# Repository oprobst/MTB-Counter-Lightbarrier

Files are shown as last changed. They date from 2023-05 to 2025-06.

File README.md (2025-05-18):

# Lichtschranke mit Unterbrechungszähler

Diese Implementierung wurde mit dem Hintergrund erstellt, auf einem Mountain-Bike Trail die Anzahl der Durchfahrten zu messen. Mit kleineren Anpassungen, kann diese Schaltung aber auch für alles Mögliche verwendet werden.

* Ziel ist es, die Unterbrechungen der Lichtschranke zu zählen. Dies wird über den gesamten Lebenszyklus, wie auch auf täglicher Basis gezählt.
* Weitere Anforderung ist ein möglichst geringer Stromverbrauch, um einen Einsatz mit Batterie im Feld zu vereinfachen.

# Bedienungsanleitung

An der rechten oberen Seite der Verteilerdose ist ein Magnetkontakt angebracht. Dieser kann genutzt werden, um das Display zu aktivieren. Sobald ein Magnet an das Gehäuse gehalten wird, aktiviert sich das Display für 5 Minuten. Im Normalbetrieb ist das Display aus, um Strom zu sparen und um zu verhindern, dass Fuchs und Hase daran herum spielen. Ein weiterer Vorteil des Magneten liegt darin, dass eine fehleranfällige Gehäusedurchführung für einen Taster eingespart werden kann.

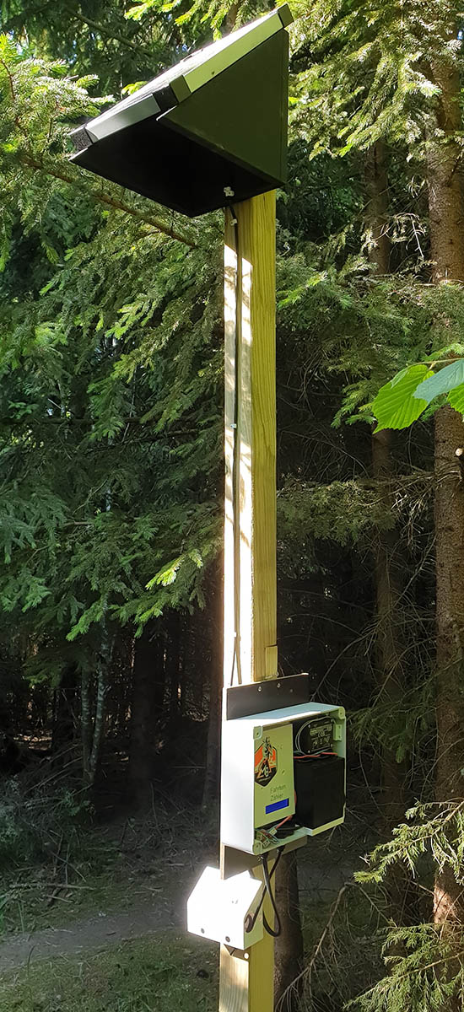
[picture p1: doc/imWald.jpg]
Installation des Zählers im Wald


## Display
Auf dem Display sind mehrere Zahlen abgebildet. Links oben ist die Gesamtzahl der aufgezeichneten Unterbrechungen. Diese Zahl wird mit jeder Durchfahrt um einen Zähler erhöht.

In der unteren Zeile sind die vergangenen Tage dokumentiert. Es wird immer dann eine neue Zählung begonnen, wenn der Helligkeitssensor einen Sonnenaufgang registriert oder wenn das System neu gestartet (oder resettet) wird.
Dabei steht jede Zahl für einen Tag. In dem unten abgebildeten Beispiel sind am heutigen Tag 15 Fahrten, gestern 0 und vorgestern 1 Unterbrechung gemessen worden. Der Speicher lässt nur 253 Zählungen zu, finden mehr Durchfahrten an einem Tag statt, so zeigt das Display 'MAX' an. Dies beeinflusst allerdings nicht die Zählung der gesamten Durchgänge oben links.

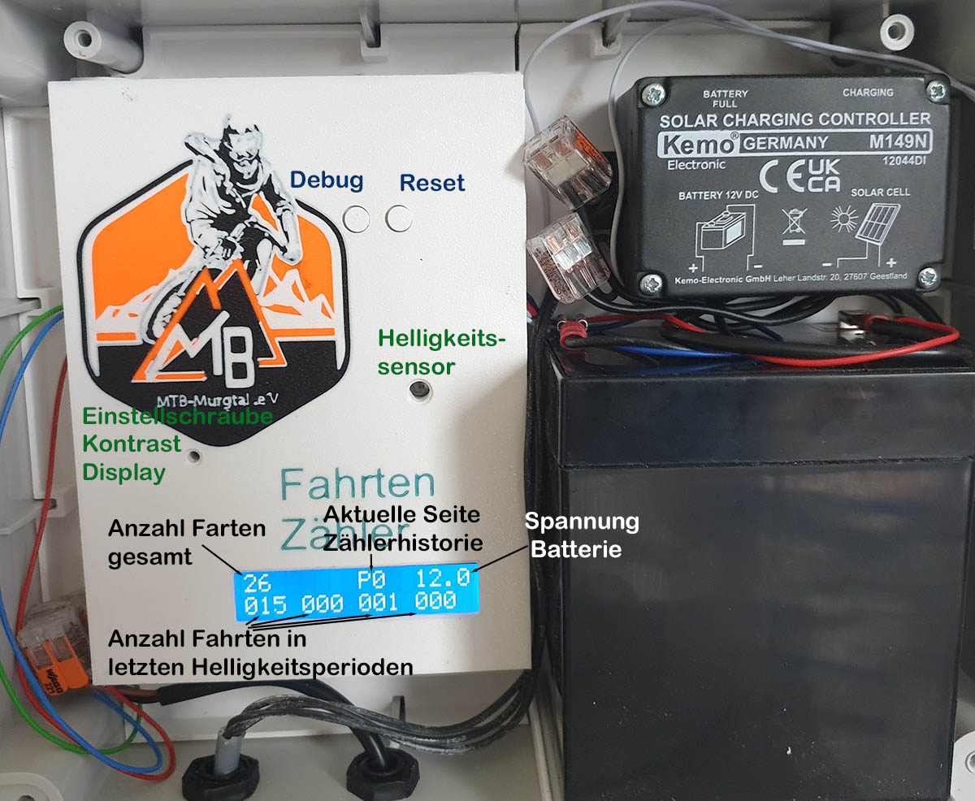
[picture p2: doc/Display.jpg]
Komponenten des Zählers


Um mehr als die letzten 4 Tage anzuzeigen, schaltet der Zähler mehrere Seiten durch. Dabei wird jede Seite wird für 5 Sekunden angezeigt. Im Beispiel befindet sich der Zähler noch auf Seite 0, visualisiert durch die Angabe 'P0'. Folglich wird in der Zeile unten auf erster Stelle der aktuelle Tag und im Weiteren die vergangenen drei Tage dargestellt.
Würde hier z.B. 'P3' stehen, so rechne man einfach die (Page)3 * 4(Tage) um auf den Tag des ersten Wertes in der Vergangenheit zu kommen. In diesem Fall würde man also die Durchfahrten von vor 12, vor 13, vor 14 und vor 15 Tagen angezeigt bekommen.

Letztlich steht ganz rechts oben eine Zahl mit einer Nachkommastelle. Hierbei handelt es sich um die aktuelle Batteriespannung. Sie muss im Regelfall zwischen 9V und 14V liegen. Liegt sie darunter, lädt die Solarzelle die Batterie nicht mehr. Liegt sie darüber, ist irgendetwas magisches passiert.

Der Kontrast des Displays lässt sich mit einer Stellschraube auf halber Höhe des Zählers einstellen.

## Zähler zurück setzen

Es ist möglich den Zähler auf 0 zurück zu setzen. Dafür muss der linke ('Debug') Knopf gedrückt und gehalten werden. Dann der rechte ('Reset' Knopf) kurz gedrückt werden, während der Debug Knopf für weitere 10 Sekunden gehalten werden muss. Das Display zählt einen Countdown herunter und meldet dann 'Speicher gelöscht'.

# Umsetzung

## Generelles Setup

Die Schaltung ist mit einer 10W Peak Solarzelle ausgestattet, die über einen Solarladeregler einen 5,4Ah Bleigelakku lädt. Diese versorgt die Schaltung über eine Sicherung (<=100mA ist ausreichend).
Aus der Versorgungsspannung wird die Lichtschranke direkt bedient und die Platine über einen 3,3V DC/DC Wandler betrieben.

Die reine Zählerschaltung (ohne den Batterie-Laderegler) benötigt - je nach Batteriespannung - etwa 4mA bei Tag und 0,7mA bei Nacht.

## Programmierung

Der Code ist nicht besonders schön und beruflich würde ich ihn dem Ersteller oder der Erstellerin um die Ohren hauen. Aber da ich das während eines Feierabend-Bierchens getippselt habe, setze ich mal andere Maßstäbe an.
Um die Programmierung einfach zu halten, werden die Arduino Libraries verwendet. Das ist nicht ganz durchgängig möglich, da die Pins für den Quarz als Input verwendet werden, was die Lib nicht vorsieht.

Wird die Lichtschranke unterbrochen, so findet für weitere 300ms keine weitere Messung mehr statt. Hierdurch wird verhindert, dass ein Arm und ein darauf folgender Oberkörper nicht als 2 Radfahrer erkannt werden.

Wird der Debug Knopf gedrückt und gehalten, so zeigt das Display den aktuell gemessenen Helligkeitswert (B:) an, sowie ein D für Day oder ein N für Night. Es folgt die Versorgungsspannungsmessung, sowie die Zählung des aktuellen Tages (C:) und die Dauer der letzten Unterbrechung (D:).

## Hardware
Als Microcontroller kommt der gute ATMega328P zum Einsatz. Um den Strombedarf gering zu halten, kommt der Zähler ohne externen Quarz und operiert auf lediglich 1 MHz per Fuses-Einstellung.
Dadurch liegt die maximale Auflösung bei 15ms. Grob über den Daumen gepeilt könnte es also sein, dass Radfahrer die mit mehr als 80 km/h auf dem Trail unterwegs sind nicht mehr erfasst werden.

Die aktuell erstellte Version wurde prototypisch auf einer Lochstreifenplatine erstellt. Spätere Versionen können bei erfolgreichem Dauertest auch auf professioneller gelayouteten Platinen umgesetzt werden.
Die momentane Implementierung speichert jeden Durchgang. Dadurch werden auch dann Zählungen gespeichert, wenn der Strom unerwartetet ausfällt. Nachteil ist die begrenzte Haltbarkeit des Speicherchips, der nur 100.000 Speichervorgänge garantiert.
Der Chip ist auf einen Sockel gesteckt und kann so einfach getauscht werden.

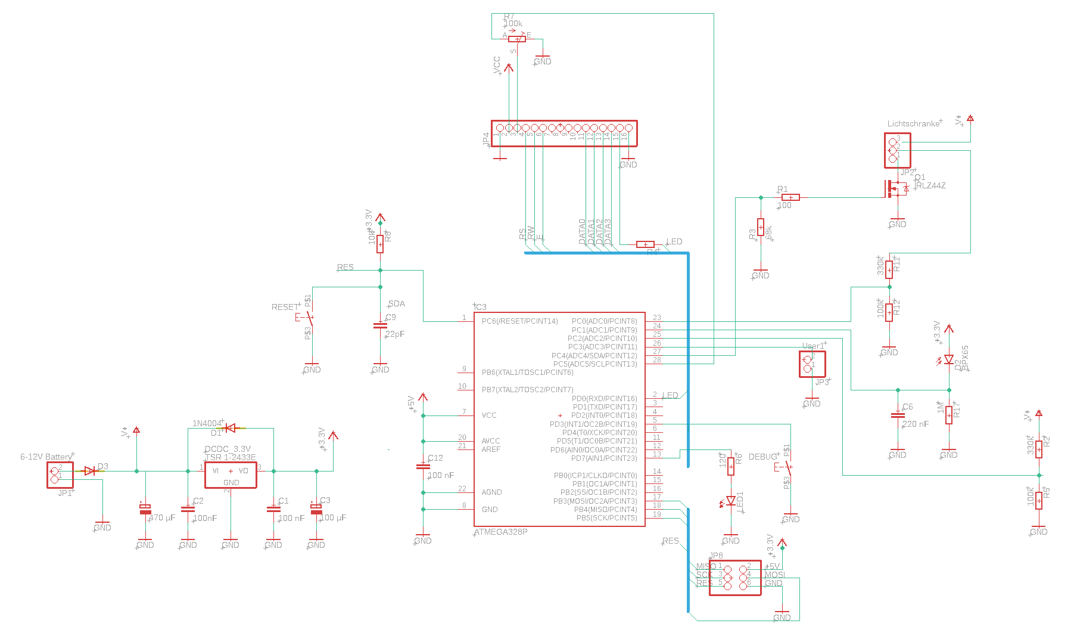
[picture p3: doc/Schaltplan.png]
Schaltplan


Generell sind die Widerstände eher großzügig zu Lasten den Genauigkeit dimensioniert mit dem Hintergedanken Strom zu sparen.

Die aktuelle Version arbeitet mit einem Hitatchi Display. Ich denke in den nächsten Versionen sollte ich dem Ganzen ein LCD Display spendieren, das ist irgendwie cooler und braucht auch nicht ganz so viele Datenleitungen. 

Als Phototransistor kommt der BP 103B-2 zum Einsatz. Für diesen Zweck nicht optimal, aber ich habe ihn mit einem sehr hohen Widerstand und einem Kondensator gebändigt. Dadurch ist die Messung sehr ungenau, aber um Hell und Dunkel zu unterscheiden reicht es.

Ein Verpolungsschutz wird durch eine Diode in Durchgangsrichtung realisiert. Auf die 0,7 Volt kommt es auch nicht mehr an. 

Zum Programmieren ist ein 6 poliger Standard Pinheader vorgesehen. Theoretisch muss man aufpassen, dass der Programmer mit 3,3V arbeitet, praktisch kann das Teil eine kurze Überspannung auf 5 V während des Programmierens ab.

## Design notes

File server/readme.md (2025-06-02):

🚴 Bike Counter API (Arduino Fahrrad-Zähler Schnittstelle)
Diese API dient als Schnittstelle für einen Arduino-basierten Fahrradzähler. Sie empfängt tägliche Zähldaten und einzelne Fahrten vom Arduino und speichert sie in einer MariaDB-Datenbank. Darüber hinaus bietet sie verschiedene Endpunkte zum Abrufen von Zähldaten, Tageszusammenfassungen und zum Export in CSV-Formaten.

🌟 Features
POST-Endpunkt: Empfängt tägliche Berichte (Gesamtzählung, Batteriestatus, Start-/Endzeiten und individuelle Fahrten-Zeitstempel) vom Arduino.
GET-Endpunkte:
Tägliche Zusammenfassungen der Fahrten.
Einzelne Fahrten für spezifische Tage (JSON).
CSV-Export von einzelnen Fahrten (/api/rides-csv) mit Zählernummer, Datum und Uhrzeit.
CSV-Export von täglichen Berichten (/api/report-csv) mit aggregierten Tagesdaten.
Abfrage des aktuellen Batteriestatus.
Abfrage des aktuellen Gesamtzählerstands.
API-Statusprüfung.
Authentifizierung: Basic Authentication für den POST-Endpunkt.
Datenbank: MariaDB (getestet mit MariaDB 10).
Technologie: PHP 8.3.
🛠️ Installation
Voraussetzungen
Webserver (z.B. Apache, Nginx) mit PHP 8.3 oder höher
MariaDB 10 oder höher Datenbankserver
Ein Datenbankbenutzer mit den notwendigen Berechtigungen (SELECT, INSERT, UPDATE, DELETE auf die bike_counter Datenbank)
1. Datenbank einrichten
Die benötigte Datenbank- und Tabellenstruktur ist in der Datei MariaDB-DDL.sql im Projektverzeichnis definiert. Führe dieses Skript auf deinem MariaDB-Server aus:

Bash

mysql -u your_db_user -p < MariaDB-DDL.sql
Oder führe den Inhalt manuell über ein Tool wie phpMyAdmin oder DBeaver aus.

SQL

-- Inhalt von MariaDB-DDL.sql
CREATE DATABASE IF NOT EXISTS `bike_counter` CHARACTER SET utf8mb4 COLLATE utf8mb4_unicode_ci;

USE `bike_counter`;

CREATE TABLE IF NOT EXISTS `daily_reports` (
    `id` INT AUTO_INCREMENT PRIMARY KEY,
    `transmission_date` DATETIME NOT NULL,
    `measurement_date` DATE NOT NULL UNIQUE,
    `start_time` TIME NOT NULL,
    `end_time` TIME NOT NULL,
    `daily_count` INT NOT NULL DEFAULT 0,
    `total_count_ever` INT NOT NULL DEFAULT 0,
    `battery_voltage` DECIMAL(4, 2) NOT NULL,
    `created_at` TIMESTAMP DEFAULT CURRENT_TIMESTAMP,
    `updated_at` TIMESTAMP DEFAULT CURRENT_TIMESTAMP ON UPDATE CURRENT_TIMESTAMP
) ENGINE=InnoDB DEFAULT CHARSET=utf8mb4 COLLATE=utf8mb4_unicode_ci;

CREATE TABLE IF NOT EXISTS `bike_rides` (
    `id` INT AUTO_INCREMENT PRIMARY KEY,
    `daily_report_id` INT NOT NULL,
    `measurement_date` DATE NOT NULL,
    `ride_time` TIME NOT NULL,
    `second_of_day` INT NOT NULL,
    `created_at` TIMESTAMP DEFAULT CURRENT_TIMESTAMP,
    CONSTRAINT `fk_daily_report`
        FOREIGN KEY (`daily_report_id`) REFERENCES `daily_reports`(`id`)
        ON DELETE CASCADE
) ENGINE=InnoDB DEFAULT CHARSET=utf8mb4 COLLATE=utf8mb4_unicode_ci;

-- Optional: Falls eine View daily_ride_summary existiert oder erstellt werden soll
-- CREATE VIEW daily_ride_summary AS ...;
2. API-Dateien hochladen
Lade die bike_counter.php-Datei (und alle anderen relevanten Dateien wie openapi.yaml, config-template.properties, MariaDB-DDL.sql in dein Webserver-Verzeichnis hoch (z.B. htdocs/mtb-club/). Die öffentliche URL sollte dann etwa https://www.your-domain.de/mtb-club/bike_counter.php/ sein.

3. Konfiguration (config.properties)
Das Projekt enthält die Datei config-template.properties. Um die API zu konfigurieren, führe folgende Schritte aus:

Benenne die Datei config-template.properties um in config.properties.
Fülle die umbenannte Datei mit deinen tatsächlichen Zugangsdaten und Einstellungen.
<!-- end list -->

Properties

# Inhalt von config-template.properties (Beispiel)
# Datenbank-Zugangsdaten
DB_HOST=localhost
DB_PORT=3306
DB_NAME=bike_counter
DB_USER=your_db_user
DB_PASSWORD=your_db_password
DB_CHARSET=utf8mb4

# API Basic Authentication
BASIC_AUTH_USER=your_api_username
BASIC_AUTH_PASSWORD=your_api_password

# API Pfad-Tiefe (Anzahl der Segmente vor /api/ im URL-Pfad, z.B. 2 für /mtb-club/bike_counter.php/api)
API_DEPTH=2 # Passe dies an deine Server-Umgebung an!

# Zeitzone für Zeitstempel (z.B. Europe/Berlin, America/New_York)
TIMEZONE=Europe/Berlin

# Minimale und maximale Batteriespannung für Validierung (optional)
MIN_BATTERY_VOLTAGE=10.0
MAX_BATTERY_VOLTAGE=15.0

# Debug-Modus (optional, 'true' oder 'false')
DEBUG_MODE=false

# API Version (optional)
API_VERSION=1.0
Wichtig: Die config.properties sollte niemals in einem öffentlichen Repository eingecheckt werden, da sie sensible Daten (Passwörter) enthält. Sie ist in der .gitignore-Datei dieses Projekts aufgeführt.

4. Datei-Encoding prüfen
Stelle sicher, dass die bike_counter.php-Datei selbst als UTF-8 ohne BOM gespeichert ist. Dies ist entscheidend für die korrekte Anzeige von Umlauten und Sonderzeichen in der API-Ausgabe und den CSV-Dateien.

🚀 Nutzung der API
Alle API-Endpunkte beginnen mit https://www.oliver-probst.de/mtb-club/bike_counter.php/api/.

POST-Endpunkte
POST /daily-report: Empfängt einen JSON-Payload mit täglichen Zähldaten und einzelnen Fahrten.
Authentifizierung: Basic Auth erforderlich.
Siehe OpenAPI Spezifikation für Details zum Request Body.
GET-Endpunkte
GET /daily-summary: Ruft tägliche Zusammenfassungen der Fahrten ab.
Query-Parameter: start_date=YYYY-MM-DD, end_date=YYYY-MM-DD
GET /rides: Ruft einzelne Fahrten für einen bestimmten Tag ab (JSON-Format).
Query-Parameter: date=YYYY-MM-DD
GET /rides-csv: Lädt eine CSV-Datei mit allen einzelnen Fahrten herunter (enthält Zählernummer pro Durchfahrt, Datum, Uhrzeit).
Query-Parameter: start_date=YYYY-MM-DD, end_date=YYYY-MM-DD
GET /report-csv: Lädt eine CSV-Datei mit den täglichen Berichten (Tageszusammenfassungen) herunter.
Query-Parameter: start_date=YYYY-MM-DD, end_date=YYYY-MM-DD
GET /battery-status: Ruft den letzten aufgezeichneten Batteriestatus ab.
GET /total-count: Ruft den letzten aufgezeichneten Gesamtzählerstand ab.
GET /status: Überprüft den API-Status und die Version.
📄 OpenAPI Spezifikation
Eine vollständige OpenAPI 3.0 Spezifikation der API befindet sich im Projektverzeichnis. Du kannst sie in Tools wie Swagger UI oder Postman importieren, um die API interaktiv zu erkunden und zu testen.

Link zur openapi.yaml

📝 Lizenz
Dieses Projekt ist unter der MIT-Lizenz lizenziert. Weitere Informationen findest du in der LICENSE-Datei. ---
Hinweis: Ersetze die Platzhalter wie https://www.your-domain.de/mtb-club/bike_counter.php/ und den Pfad zum Logo durch deine tatsächlichen Werte. Du solltest auch eine LICENSE-Datei hinzufügen, wenn du eine Lizenz angeben möchtest.

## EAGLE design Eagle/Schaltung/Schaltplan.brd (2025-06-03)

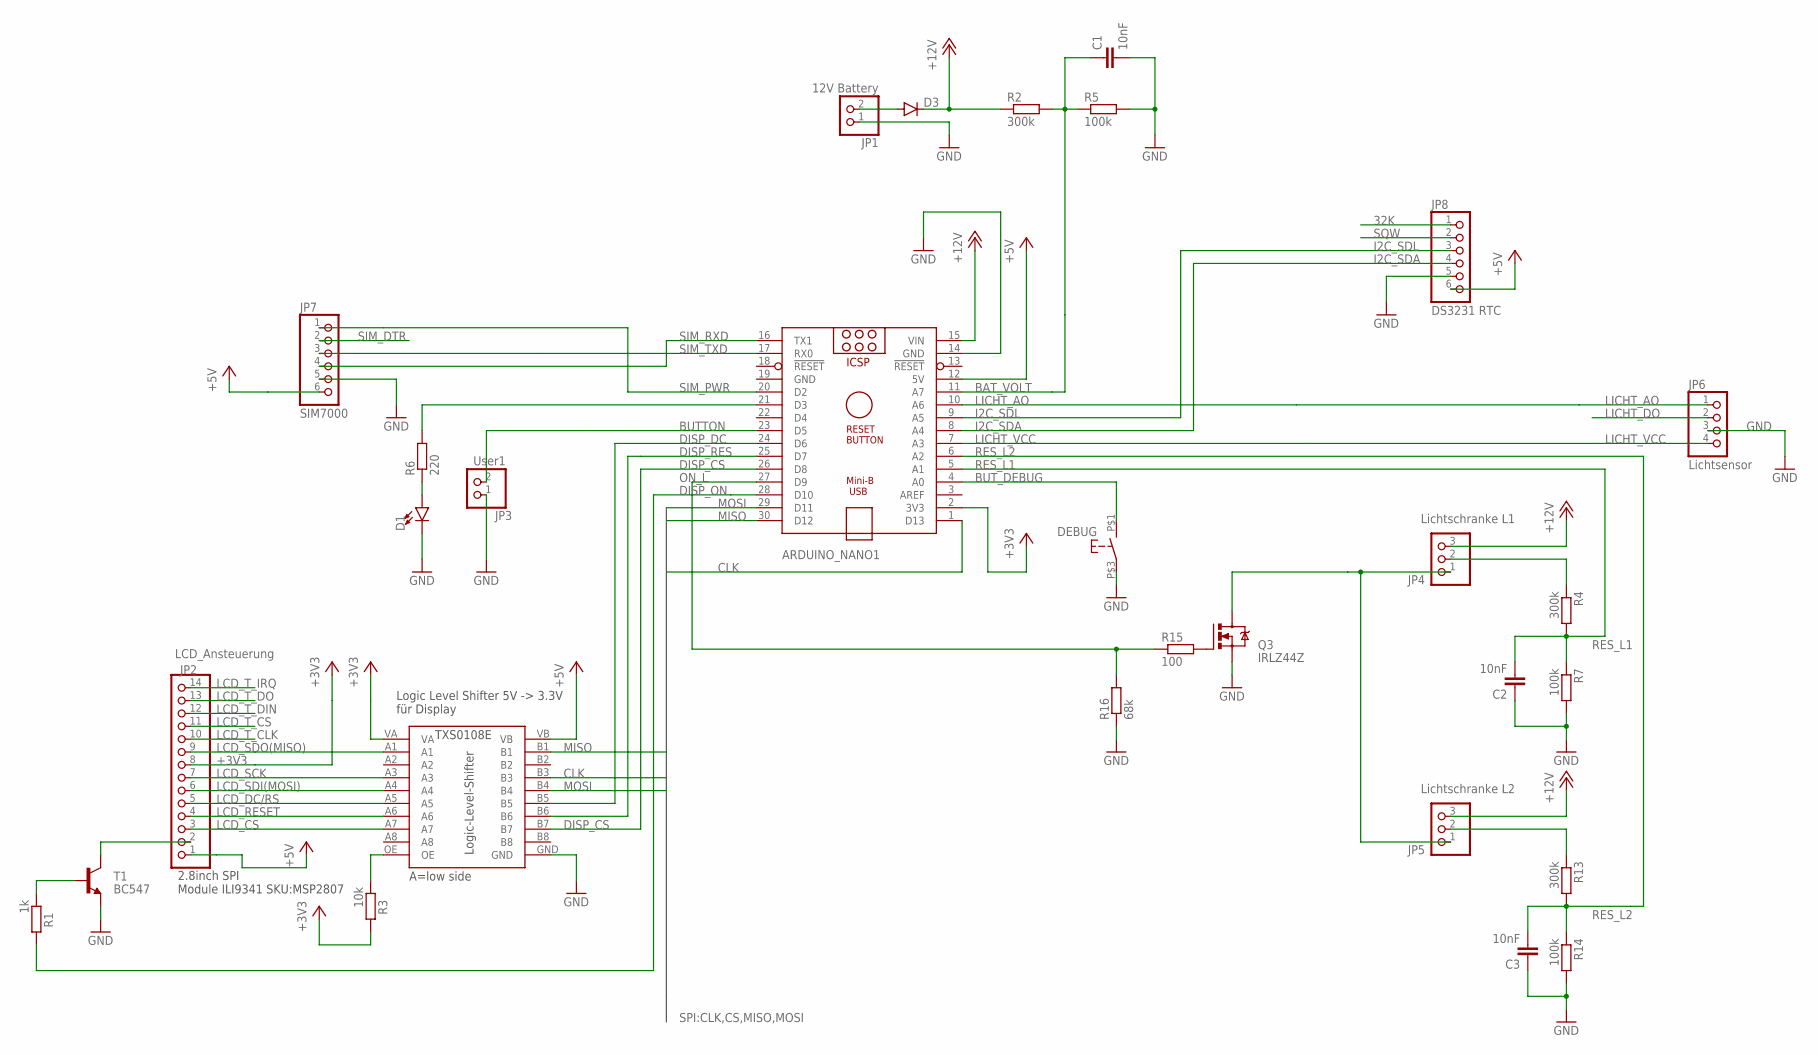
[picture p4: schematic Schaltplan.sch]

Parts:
ARDUINO_NANO1: ARDUINO_NANO
C1, C2, C3: 10nF; C0805K
D1: LED5MM; LED_5MM
D3: 1N4004; DO41-10
DEBUG: SCHLIESSER_TASTSCHALTER; B3F-10XX
JP1: 12V Battery; 1X02
JP2: LCD_Ansteuerung; 1X14
JP3: User1; 1X02
JP4: Lichtschranke L1; 1X03
JP5: Lichtschranke L2; 1X03
JP6: Lichtsensor; 1X04
JP7: SIM7000; 1X06
JP8: DS3231 RTC; 1X06
Q3: IRLZ44Z; TO220BH
R1: 1k; R1206
R2, R4, R13: 300k; R1206
R3: 10k; R1206
R5, R7, R14: 100k; R1206
R6: 220; R1206
R15: 100; R1206
R16: 68k; R1206
T1: BC547; TO92
U$2: TXS0108E_LOGIC_LEVEL_SHIFTER

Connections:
32K: JP8.1
+3V3: ARDUINO_NANO1.2 (3V3), JP2.8, R3.2, U$2.VA
+5V: ARDUINO_NANO1.12 (5V), JP2.1, JP7.6, JP8.6, U$2.VB
+12V: ARDUINO_NANO1.15 (VIN), D3.C, JP4.3, JP5.3, R2.1
BAT_VOLT: ARDUINO_NANO1.11 (A7), C1.1, R2.2, R5.1
BUTTON: ARDUINO_NANO1.23 (D5), JP3.2
BUT_DEBUG: ARDUINO_NANO1.4 (A0), DEBUG.P$1 (3)
CLK: ARDUINO_NANO1.1 (D13), U$2.B3
DISP_CS: ARDUINO_NANO1.26 (D8), U$2.B7
DISP_DC: ARDUINO_NANO1.24 (D6), U$2.B5
DISP_ON: ARDUINO_NANO1.28 (D10), R1.2
DISP_RES: ARDUINO_NANO1.25 (D7), U$2.B6
GND: ARDUINO_NANO1.14 (GND), ARDUINO_NANO1.19 (GND), C1.2, C2.1, C3.1, D1.K (C), DEBUG.P$3 (4), JP1.1, JP3.1, JP6.3, JP7.5, JP8.5, Q3.S, R5.2, R7.2, R14.2, R16.1, T1.1 (E), U$2.GND
I2C_SDA: ARDUINO_NANO1.8 (A4), JP8.4
I2C_SDL: ARDUINO_NANO1.9 (A5), JP8.3
LCD_CS: JP2.3, U$2.A7
LCD_DC/RS: JP2.5, U$2.A5
LCD_RESET: JP2.4, U$2.A6
LCD_SCK: JP2.7, U$2.A3
LCD_SDI(MOSI): JP2.6, U$2.A4
LCD_SDO(MISO): JP2.9, U$2.A1
LCD_T_CLK: JP2.10
LCD_T_CS: JP2.11
LCD_T_DIN: JP2.12
LCD_T_DO: JP2.13
LCD_T_IRQ: JP2.14
LICHT_AO: ARDUINO_NANO1.10 (A6), JP6.1
LICHT_DO: JP6.2
LICHT_VCC: ARDUINO_NANO1.7 (A3), JP6.4
MISO: ARDUINO_NANO1.30 (D12), U$2.B1
MOSI: ARDUINO_NANO1.29 (D11), U$2.B4
unnamed: JP5.2, R13.1
unnamed: D3.A, JP1.2
unnamed: JP2.2, T1.3 (C)
unnamed: ARDUINO_NANO1.21 (D3), R6.2
unnamed: JP4.1, JP5.1, Q3.D
unnamed: R1.1, T1.2 (B)
unnamed: D1.A, R6.1
unnamed: R3.1, U$2.OE
unnamed: Q3.G, R15.2
unnamed: JP4.2, R4.1
ON_L: ARDUINO_NANO1.27 (D9), R15.1, R16.2
RES_L1: ARDUINO_NANO1.5 (A1), C2.2, R4.2, R7.1
RES_L2: ARDUINO_NANO1.6 (A2), C3.2, R13.2, R14.1
SIM_DTR: JP7.2
SIM_PWR: ARDUINO_NANO1.20 (D2), JP7.1
SIM_RXD: ARDUINO_NANO1.16 (TX1), JP7.4
SIM_TXD: ARDUINO_NANO1.17 (RX0), JP7.3
SQW: JP8.2

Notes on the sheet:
A=low side
2.8inch SPI Module ILI9341 SKU:MSP2807
Logic Level Shifter 5V -> 3.3V für Display

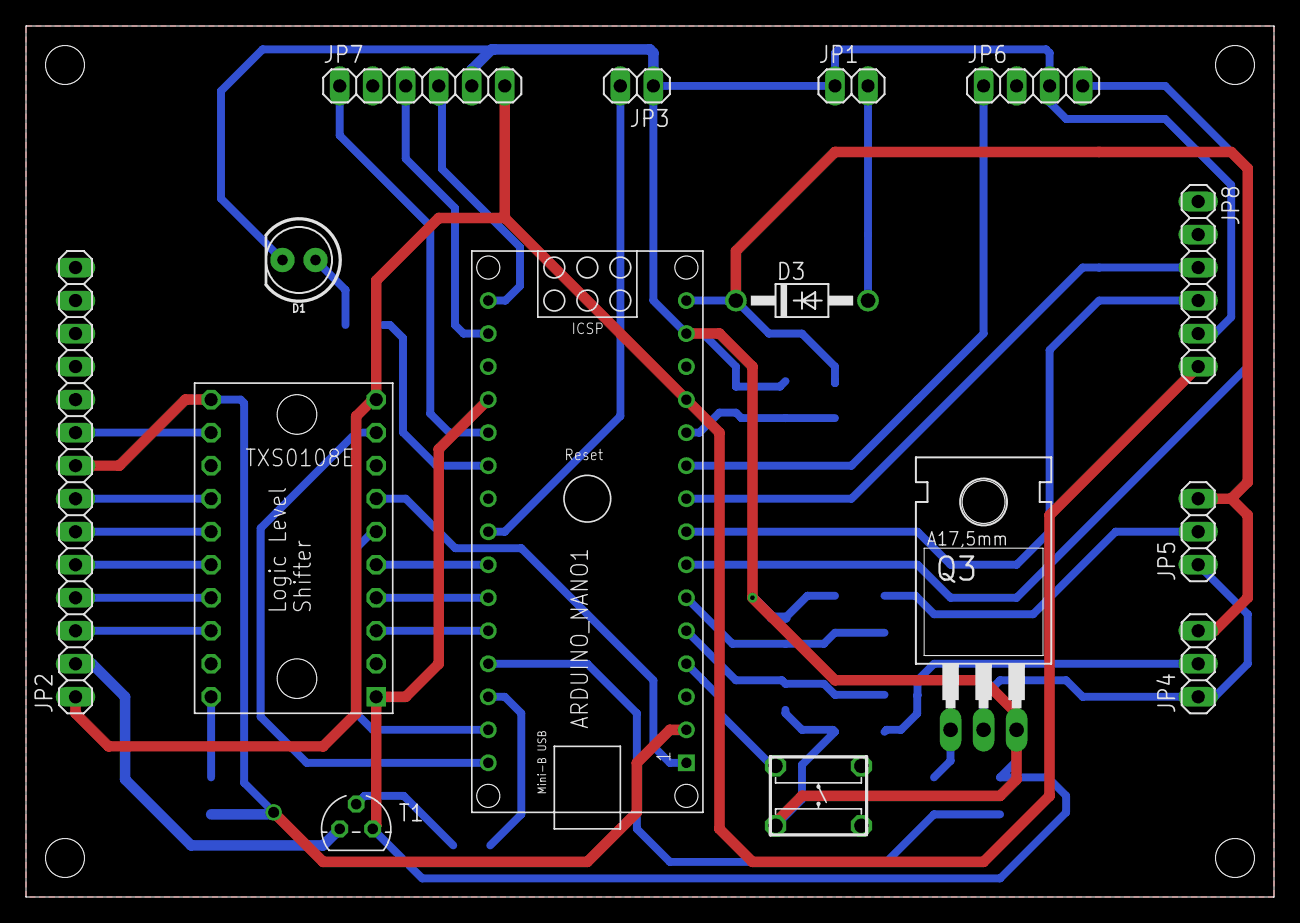
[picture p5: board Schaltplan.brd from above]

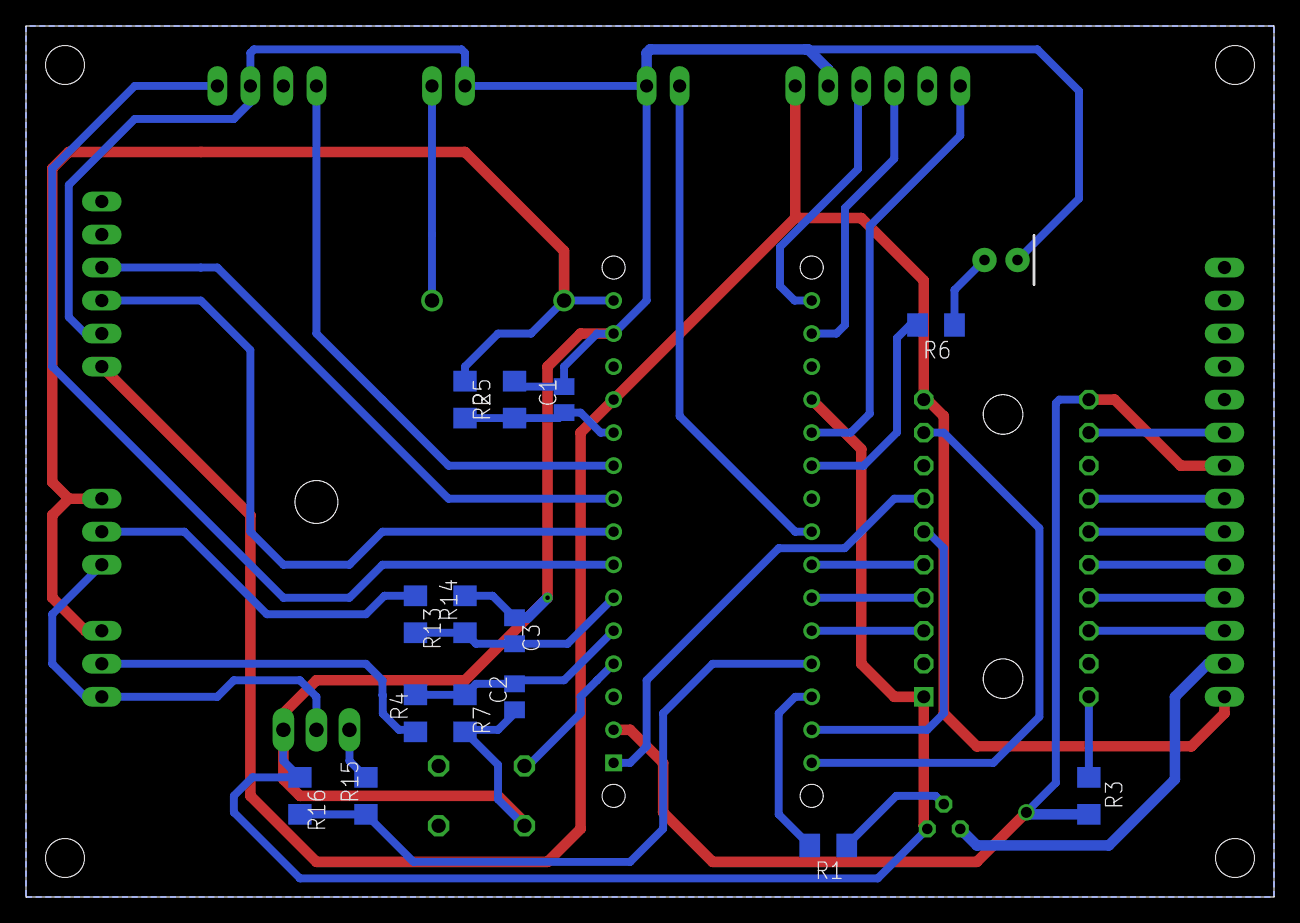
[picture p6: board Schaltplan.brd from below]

Board: 2 copper layers, 96.0 x 67.0 mm, 29 parts (14 on the bottom side), 40 nets.

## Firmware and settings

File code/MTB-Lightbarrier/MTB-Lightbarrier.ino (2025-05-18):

#define ON 1
#define OFF 0

#define DEBUG_LED 7
#define LCD_LED 6

#define PHOTODIODE_ON 0
#define PHOTODIODE A5

#define LIGHTBARRIER_ON 4
#define LIGHTBARRIER A3
#define LIGHTBARRIER2 A2

#define BATTERY_VOLTAGE A4

#define DEBUG_BUTTON 3

#define CHECK_FOR_DAYLIGHT_EVERY 120000  //ms how often to check daylight

#define DURATION_DISPLAY_ON 300000  //ms how long the display should stay on
#define CYCLES_TO_WAIT 4           // multiplied with 8sec = time to wait between brightness checks to wake up from night sleep


#define LIMIT_NIGHT 14             // Measured limit to activate night mode
#define LIMIT_DAY 30               // Measured limit to activate day mode
#define MEASUREMENTS_LIMIT 5       //consecutive measurements below LIMIT_NIGHT required before power down.
#define HOURS_DAY_MIN 10           //minimum hours it must run every day before checking daylight

#include <LiquidCrystal.h>  
#include <avr/wdt.h>
#include <avr/sleep.h>
#include <EEPROM.h>

/* Fuses:
 -U lfuse:w:0x62:m -U hfuse:w:0xD1:m -U efuse:w:0xFF:m -U lock:w:0x3F:m

  //EEPROM address > 12: each byte represents a single day. Memory entries have the following meaning:
  // 255 = invalid memory range
  // 254 = null / empty
  // 253 = maximum
  // 0-252 = amount of bikers crossed.

*/

LiquidCrystal lcd(8, 9, 10, 2, 5, A0, A1);

// indicates display on or off
bool displayOn = true;
// millis, when to stop display
long millisDisplayOff = 0;

//when to check for the next daylight
long nextMillisToCheckForDaylight = millis() + CHECK_FOR_DAYLIGHT_EVERY;

//number of brightness measurements below cutoff value
short countOfMeasurementsOfNight = 0;
//indicating night
bool isDay = true;
//counter for pwr down check on watchdog interrupt
short pwrdwnCycles = 0;
//duration of last barrier contact
long lastContactDuration = 0;

//The day of recording
long currentDayCycle = 1;

long todayStartedAtMillis = millis();

// EEPROM Location to store todays count.
int todaysEepromByteAddress = 0;

// millis when last display content was updated.
long lastDisplayUpdate = millis();

// when the last daylight recording page was switched
long lastDisplayPageSwitch = millis();

//count of contacts today
int todayCount = 0;
long overallCount;

//indicates if the Light barrier is durable blocked (longer than 2 sec).
bool permanentBlocked = false;

//pagination of stored daylight recordings
int page = 0;
// last measurements during past daycycles
short pageContent[4] = { 0, 0, 0, 0 };

//daymode of the last check: react only on changes
bool lastDayMode = false;

/*
 * Here we go
 */
void setup() {

  pinMode(DEBUG_LED, OUTPUT);
  pinMode(LCD_LED, OUTPUT);
  pinMode(PHOTODIODE_ON, OUTPUT);
  pinMode(PHOTODIODE, INPUT);
  pinMode(LIGHTBARRIER_ON, OUTPUT);
  pinMode(LIGHTBARRIER, INPUT);
  pinMode(LIGHTBARRIER2, INPUT);
  pinMode(DEBUG_BUTTON, INPUT_PULLUP);
  //Pin6 is not arduino API compatible, need to set it manually:
  DDRB &= ~(1 << PB6);  //input
  PORTB |= (1 << PB6);  //pullup

  digitalWrite(LCD_LED, HIGH);
  digitalWrite(PHOTODIODE_ON, HIGH);
  digitalWrite(LIGHTBARRIER_ON, HIGH);
  digitalWrite(DEBUG_LED, LOW);

  lcd.begin(16, 2);
  lcd.clear();
  lcd.setCursor(0, 0);  //col, row
  lcd.print("MTB-Murgtal e.V.");
  lcd.setCursor(0, 1);  //col, row
  lcd.print("Fahrtenzaehler");

  for (short i = 0; i < 4; i++) {
    debugLED(ON);
    delay(250);
    debugLED(OFF);
    delay(250);
  }

  if (readDebugButton()) {
    resetMemory();
  }
  overallCount = readOverallCount();
  determineTodayStorageByte();
  storeTodayCount();
  watchdogSetup();
  activateDisplay(ON);
}


/*
 * Reset memory, if Debug button is pushed on startup for > 9 sec.
 */
void resetMemory() {
  for (short i = 9; i > 0; i--) {    
    lcd.clear();
    lcd.setCursor(0, 0);  //col, row
    lcd.print("Loesche Speicher");
    lcd.setCursor(0, 1);  //col, row
    lcd.print(i);
    lcd.print(" sec. halten");
    delay(1000);
    if (!readDebugButton()) return;
  }
  lcd.clear();
  for (int i = 13; i < EEPROM.length(); i++) {
    EEPROM.write(i, 254);
  }
  for (int i = 0; i < 13; i++) {
    EEPROM.write(i, 0);
  }

  lcd.setCursor(0, 0);  //col, row
  lcd.print("Speicher");  
  lcd.setCursor(0, 1);  //col, row
  lcd.print("geloescht");
  delay (2000);
}

void loop() {

  checkBarrier();


  if(displayOn){
    //update display every 0,5 sec if on:
    if (lastDisplayUpdate + 500 < millis()) {
      showOutput();
      lastDisplayUpdate = millis();
    }

    if (lastDisplayPageSwitch + 10000 < millis()) {
      page++;
      lastDisplayPageSwitch = millis();
    }

    if (millisDisplayOff < millis()) activateDisplay(OFF);
  }
  // check if debug button is pushed
  if (readDebugButton()) {
    debugLED(ON);
    activateDisplay(ON);
    showDebugOutput();
    delay(200);
    debugLED(OFF);
  }

  // check if user button is pushed
  if (readUserButton()) {
    page = 0;
    lastDisplayPageSwitch = millis();
    debugLED(ON);
    activateDisplay(ON);
    showOutput();
    delay(200);
    debugLED(OFF);
  }

  if (isDay) {
    if (nextMillisToCheckForDaylight < millis()) {
      checkForDaylight();     
    }

  } else if (!isDay) {  
    wdt_reset();
    set_sleep_mode(SLEEP_MODE_PWR_DOWN);  // choose power down mode
    sleep_mode();                         // sleep now!

    if (pwrdwnCycles++ > CYCLES_TO_WAIT) {  // After CYCLES_TO_WAIT wakeups by the watchdog timer, check for brightness
      pwrdwnCycles = 0;
      delay(100);
      checkForDaylight();
    }
  }
}


/* 
 * Check barrier is blocked
 */
bool checkBarrier() {
  long startContact = millis();
  bool detection = false;
  permanentBlocked = false;
  while (objectDetected()) {
    // delay(1);
    detection = true;
    if (millis() > startContact + 2000) {
      for (short i = 0; i < 10; i++) {
        debugLED(ON);
        delay(200);
        debugLED(OFF);
        delay(50);
      }
      permanentBlocked = true;
      return false;
    }
  }
  if (detection) {
    lastContactDuration = millis() - startContact;
    storeOverallCount(++overallCount);      
    todayCount++;
    storeTodayCount();    
    debugLED(ON);
    delay(50);
    debugLED(OFF);
    delay(50);    
    debugLED(ON);
    delay(50);
    debugLED(OFF);
    delay(50);
    debugLED(ON);
    delay(50);
    debugLED(OFF);
  }
}


/*
 * Visualize current count, battery voltage and last daylight period counts
 */
void showOutput() {

  lcd.clear();
  lcd.noCursor();
  lcd.setCursor(0, 0);  //col, row
  lcd.print(overallCount);


  lcd.setCursor(12, 0);  //col, row
  lcd.print(readBatteryVoltage(), 1);
  lcd.print("V");


  if (permanentBlocked) {
    lcd.setCursor(0, 1);  //col, row
    lcd.print("LS BLOCKIERT    ");
  } else {
    if (overallCount < 100000000) {
      lcd.setCursor(8, 0);
      lcd.print("P");
    }
    lcd.print(page);
    lcd.setCursor(0, 1);  //col, row
    getDaylightRecordings();
    for (short i = 0; i < 4; i++) {
      if (pageContent[i] >= 254) {
        lcd.print("---");
      } else if (pageContent[i] == 253) {
        lcd.print("MAX");
      } else {
        if (pageContent[i] < 100) lcd.print("0");
        if (pageContent[i] < 10) lcd.print("0");
        lcd.print(pageContent[i]);
      }
      lcd.print(" ");
    }
  }
}


/*
 * Show some debug output on lcd display
 */
void showDebugOutput() {
  digitalWrite(PHOTODIODE_ON, HIGH);
  delay(25);
  int brightness = analogRead(PHOTODIODE);
  digitalWrite(PHOTODIODE_ON, LOW);
  int barrier = analogRead(LIGHTBARRIER);

  lcd.clear();
  lcd.noCursor();
  lcd.setCursor(0, 0);  //col, row
  lcd.print("B:");
  lcd.print(brightness);
  if (isDay) {
    lcd.print("D");
  } else {
    lcd.print("N");
  }

  lcd.setCursor(12, 0);  //col, row
  lcd.print(readBatteryVoltage(), 1);
  lcd.print("V");

  lcd.setCursor(0, 1);
  lcd.print("C:");
  lcd.print(todayCount);

  lcd.setCursor(4, 1);
  lcd.print(" t:");
  lcd.print(lastContactDuration);

 // lcd.setCursor(9, 1);
  //lcd.print(analogRead(LIGHTBARRIER));
  //lcd.print("|");
  //lcd.print(analogRead(LIGHTBARRIER2));
}

/* 
 * True as long as the debug debug button is active.
 */
bool readDebugButton() {
  return (digitalRead(DEBUG_BUTTON) == LOW);
}

/*
 * True as long as the User debug button is active.
 * Workaround for missing Pin6 digitalRead of arduino API (due to not used crystal)
 */
bool readUserButton() {
  return !(PINB & (1 << PB6));
}

/*
 * Turn debugLED on/off
 */
void debugLED(bool on) {
  digitalWrite(DEBUG_LED, on);
}

/*
 * Will check for brightness. 
 * If the brightness is measured MEASUREMENT_LIMIT times higher than defined LIMIT_DAY, this method will returns always true. 
 * If the brightness is measured MEASUREMENT_LIMIT times lower then defined LIMIT_NIGHT, this method will returns always false.
 */
bool checkForDaylight() {
  if (todayStartedAtMillis + (HOURS_DAY_MIN * 3600000) > millis()) {
    return isDay;  // do not enter night mode before HOURS_DAY_MIN h daylight runtime
  }
  digitalWrite(PHOTODIODE_ON, HIGH);
  delay(50);
  if (isDay) {
    if (analogRead(PHOTODIODE) < LIMIT_NIGHT) {
      countOfMeasurementsOfNight++;
    }
    if (countOfMeasurementsOfNight >= MEASUREMENTS_LIMIT) {
      isDay = false;
      countOfMeasurementsOfNight = 0;
      debugLED(ON);
      delay(200);
      debugLED(OFF);
      digitalWrite(PHOTODIODE_ON, LOW);
      digitalWrite(LIGHTBARRIER_ON, LOW);
      storeTodayCount();
    }
  } else {
    if (analogRead(PHOTODIODE) > LIMIT_DAY) {
      isDay = true;      
      digitalWrite(PHOTODIODE_ON, HIGH);
      digitalWrite(LIGHTBARRIER_ON, HIGH);
      debugLED(ON);
      delay(500);
      debugLED(OFF);
      todayStartedAtMillis = millis();  //set start of the day to now
      todayCount = 0;
      determineTodayStorageByte();     
    }
  }
  digitalWrite(PHOTODIODE_ON, LOW);
  nextMillisToCheckForDaylight = millis() + CHECK_FOR_DAYLIGHT_EVERY;
  return isDay;
}



/*
 * Turn display ON/OFF
 */
void activateDisplay(bool on) {
  if (!on) {
    digitalWrite(LCD_LED, LOW);
    lcd.noDisplay();
    displayOn = false;
  } else {
    digitalWrite(LCD_LED, HIGH);
    lcd.display();
    displayOn = true;
    millisDisplayOff = millis() + DURATION_DISPLAY_ON;
  }
}

/* 
 *  Measure Battery voltage
 */
double readBatteryVoltage() {
  return 14.3 / 1023.0 * (double)analogRead(BATTERY_VOLTAGE) + 1.0d;
}


/* 
 *  returns true, when something blocks the light barrier
 */
bool objectDetected() {
  int start = millis();////////////
  int waitFor = 2500;
  if (analogRead(LIGHTBARRIER) > 100){
    while (waitFor-- > 0) {
       if (analogRead(LIGHTBARRIER2) > 100) {  
        return true;
       }
       //delay (1);
     }
  } else if (analogRead(LIGHTBARRIER2) > 100){
     while (waitFor-- > 0) {
       if (analogRead(LIGHTBARRIER) > 100){
          return true;
       }
      //delay (1);
     }  
  }
  return false;
}


/*
 * Search for the first free EEPROM Address to store today's count later there.
 */
int determineTodayStorageByte() {
  todaysEepromByteAddress = 12;
  short value = 1;
  while (value != 254 && todaysEepromByteAddress++ < EEPROM.length() - 1) {
    value = EEPROM.read(todaysEepromByteAddress);
  }  //found next empty entry
  if (todaysEepromByteAddress >= EEPROM.length() - 1) {
    todaysEepromByteAddress = 12;
  }
  return todaysEepromByteAddress;
}


void getDaylightRecordings() {
  long address = todaysEepromByteAddress - 4 * page;
  for (short i = 3; i >= 0; i--) {
    if (address - i > 12) {
      pageContent[i] = EEPROM.read(address - i);
    } else {
      pageContent[i] = 255;
    }
  }
  if (pageContent[0] == 255) {
    page = 0;
  }
}
/*
 * Store the count for today only
 */
void storeTodayCount() {
  if (todayCount > 253) {
    return;
  }
  EEPROM.write(todaysEepromByteAddress, todayCount);
  EEPROM.update(todaysEepromByteAddress + 1, 254);
}

/*
 * Read the fist 3 long value from EEPROM. Check if at least 2 of 3 have the same value and return it. If they have completely different values, return the value of address 0.
 * This is implemented to mitigate an EEPROM failure.
 */
long readOverallCount() {
  long l1 = EEPROMReadlong(0);
  long l2 = EEPROMReadlong(4);
  long l3 = EEPROMReadlong(8);

  if (l1 != l2) {
    if (l1 == l3) {
      return l1;
    } else if (l2 == l3) {
      return l2;
    } else {
      return l1;
    }
  } else {
    return l1;
  }
}

/*
 * Store the current overall count into the first 12 (3x4) byte of the EEPROM.
 */
void storeOverallCount(long value) {
  EEPROMWritelong(0, value);
  EEPROMWritelong(4, value);
  EEPROMWritelong(8, value);
}

/*
 * Read a long (4byte) value from EEPROM
 */
long EEPROMReadlong(long address) {
  long four = EEPROM.read(address);
  long three = EEPROM.read(address + 1);
  long two = EEPROM.read(address + 2);
  long one = EEPROM.read(address + 3);

  return ((four << 0) & 0xFF) + ((three << 8) & 0xFFFF) + ((two << 16) & 0xFFFFFF) + ((one << 24) & 0xFFFFFFFF);
}

/*
 * Write a long (4byte) value to EEPROM
 */
void EEPROMWritelong(int address, long value) {
  byte four = (value & 0xFF);
  byte three = ((value >> 8) & 0xFF);
  byte two = ((value >> 16) & 0xFF);
  byte one = ((value >> 24) & 0xFF);

  EEPROM.write(address, four);
  EEPROM.write(address + 1, three);
  EEPROM.write(address + 2, two);
  EEPROM.write(address + 3, one);
}


/*
 * Watchdog interrupt every 8 sec, to wake up from power down mode at night.
 */
void watchdogSetup(void) {
  cli();
  wdt_reset();
  WDTCSR |= (1 << WDCE) | (1 << WDE);
  WDTCSR = (1 << WDIE) | (0 << WDE) | (1 << WDP3) | (1 << WDP0);  // 8s / interrupt, no system reset
  sei();
}

ISR(WDT_vect) {
}

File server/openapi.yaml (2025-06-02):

openapi: 3.0.0
info:
  title: Bike Counter API
  description: |
    API für den Arduino Fahrradzähler, um Fahrten und tägliche Berichte zu empfangen und zu exportieren.
    Diese API wird von der `bike_counter.php` Datei bereitgestellt.
  version: 1.0.0 # Basierend auf dem config['API_VERSION'] Wert, kann angepasst werden
servers:
  - url: https://www.oliver-probst.de/mtb-club/bike_counter.php/api
    description: Produktionsserver

paths:
  /daily-report:
    post:
      summary: Neuen täglichen Bericht empfangen
      description: Empfängt aggregierte Tagesdaten und einzelne Fahrten von einem Arduino-Gerät.
      security:
        - basicAuth: []
      requestBody:
        required: true
        content:
          application/json:
            schema:
              type: object
              required:
                - transmission_date
                - measurement_date
                - start_second_of_day
                - end_second_of_day
                - daily_count
                - total_count_ever
                - battery_voltage
                - ride_timestamps
              properties:
                transmission_date:
                  type: string
                  format: date-time
                  description: Datum und Uhrzeit der Übertragung (YYYY-MM-DD HH:MM:SS).
                  example: "2024-06-02 14:30:00"
                measurement_date:
                  type: string
                  format: date
                  description: Datum der Messung (YYYY-MM-DD).
                  example: "2024-06-01"
                start_second_of_day:
                  type: integer
                  description: Startsekunde des Tages für die Messperiode (0-86399).
                  minimum: 0
                  maximum: 86399
                  example: 28800 # 08:00:00
                end_second_of_day:
                  type: integer
                  description: Endsekunde des Tages für die Messperiode (0-86399).
                  minimum: 0
                  maximum: 86399
                  example: 64800 # 18:00:00
                daily_count:
                  type: integer
                  description: Gesamtzahl der Fahrten für diesen Tag.
                  minimum: 0
                  example: 42
                total_count_ever:
                  type: integer
                  description: Gesamtzahl der Fahrten seit Installation.
                  minimum: 0
                  example: 123456
                battery_voltage:
                  type: number
                  format: float
                  description: Aktueller Batteriespannungswert in Volt.
                  minimum: 0.0
                  example: 12.34
                ride_timestamps:
                  type: array
                  description: Liste der Sekunden des Tages für jede einzelne Fahrt.
                  items:
                    type: integer
                    minimum: 0
                    maximum: 86399
                  example: [28805, 29120, 35600, 48100, 52000]
      responses:
        '200':
          description: Täglicher Bericht erfolgreich gespeichert.
          content:
            application/json:
              schema:
                type: object
                properties:
                  success:
                    type: boolean
                    example: true
                  message:
                    type: string
                    example: "Daily report saved successfully"
                  report_id:
                    type: integer
                    example: 123
                  rides_saved:
                    type: integer
                    example: 5
                  timestamp:
                    type: string
                    format: date-time
                    example: "2024-06-02T14:30:00+02:00"
        '400':
          $ref: '#/components/responses/BadRequest'
        '401':
          $ref: '#/components/responses/Unauthorized'
        '500':
          $ref: '#/components/responses/InternalServerError'
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

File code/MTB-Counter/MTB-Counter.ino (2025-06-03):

#include <TimeLib.h>
#include "ui.h"
#include "sim.h"
#include "debug.h"

#define ON 1
#define OFF 0



void setup() {
  initScreen();
  showSplash();

  initFona();
  //showSimSignal(getRSSI());

  syncTimeNTP ();
}

void loop() {

  turnDisplay(ON);

  showBatteryStatus(0);
  showSimSignal(getSimRSSI());
  //  getRSSI();

  

  //char timebuf[23];
  //getTime(timebuf, sizeof(timebuf));
  //parseAndSetTime(timebuf);

 
  showTime();

  /*

showToday (11);
 show4Weeks (134);
 showAllCount (17821);


  DateCount data[36] = {
        { "01.05.25", 10 },
        { "02.05.25", 20 },
        { "03.05.25", 30 },
        { "04.05.25", 40 },
        { "05.05.25", 50 },
        { "06.05.25", 60 },
        { "07.05.25", 70 },
        { "08.05.25", 80 },
        { "09.05.25", 90 },
        { "10.05.25", 100 },
        { "11.05.25", 110 },
        { "12.05.25", 120 },
        { "01.05.25", 10 },
        { "13.05.25", 20 },
        { "14.05.25", 30 },
        { "15.05.25", 40 },
        { "16.05.25", 50 },
        { "17.05.25", 60 },
        { "18.05.25", 70 },
        { "19.05.25", 80 },
        { "20.05.25", 90 },
        { "21.05.25", 100 },
        { "22.05.25", 110 },
        { "23.05.25", 120 },
        { "24.05.25", 10 },
        { "25.05.25", 20 },
        { "26.05.25", 30 },
        { "27.05.25", 40 },
        { "28.05.25", 50 },
        { "29.05.25", 60 },
        { "30.05.25", 70 },
        { "31.05.25", 80 },
        { "01.06.25", 90 },
        { "02.06.25", 100 },
        { "03.06.25", 110 },
        { "04.06.25", 120 }
    };

  showCountPerDate(data);
  showLastTransmission("Letzte Uebertragung: 25.05.2025 14:39:22,123");
  showStatus(" Status okay\n Lichtschranke okay", 0);

  

  showBatteryStatus(35);
  // delay(3010);
 showStatus(" Status Fehler\n Kein Netz", 2);
  showBatteryStatus(65);
  
 // delay(3010);

 showToday (1);
 show4Weeks (133);
 showAllCount (17811);
  showLastTransmission("Letzte Uebertragung: 18.08.2022 16:39:42,173"); 
  showStatus(" Status Fehler\n Lichtschranke blockiert", 1);
 showBatteryStatus(100);
  */
  delay(1010);
}

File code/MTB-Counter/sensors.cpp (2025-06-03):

#include "sensors.h"
// #include "debug.h" // debug.h is no longer needed if all DEBUG_PRINT* are removed
#include "store.h" // For startANewDay(), storeTodayCount(), storeOverallCount(), readOverallCount()
#include "ui.h"    // For turnDisplay()
#include "counter.h" // For updating todayCount and overallCount

#include <avr/wdt.h>
#include <avr/sleep.h>

#define PHOTODIODE_ON 0
#define PHOTODIODE A5

#define LIGHTBARRIER_ON 4
#define LIGHTBARRIER A3
#define LIGHTBARRIER2 A2

#define BATTERY_VOLTAGE A4

#define DEBUG_BUTTON 3
#define USER_BUTTON 6 // Assuming PB6 from original code corresponds to Arduino pin 6

#define CHECK_FOR_DAYLIGHT_EVERY 120000  //ms how often to check daylight
#define DURATION_DISPLAY_ON 300000  //ms how long the display should stay on
#define CYCLES_TO_WAIT 4           // multiplied with 8sec = time to wait between brightness checks to wake up from night sleep

#define LIMIT_NIGHT 14             // Measured limit to activate night mode
#define LIMIT_DAY 30               // Measured limit to activate day mode
#define MEASUREMENTS_LIMIT 5       //consecutive measurements below LIMIT_NIGHT required before power down.
#define HOURS_DAY_MIN 10           //minimum hours it must run every day before checking daylight

#define OFF 0

// indicates display on or off
bool displayOn = true;
// millis, when to stop display
long millisDisplayOff = 0;

//when to check for the next daylight
long nextMillisToCheckForDaylight = millis() + CHECK_FOR_DAYLIGHT_EVERY;

//number of brightness measurements below cutoff value
short countOfMeasurementsOfNight = 0;
//indicating night
bool isDay = true;
//counter for pwr down check on watchdog interrupt
short pwrdwnCycles = 0;
//duration of last barrier contact
long lastContactDuration = 0;

long todayStartedAtMillis = millis();

//indicates if the Light barrier is durable blocked (longer than 2 sec).
bool permanentBlocked = false;


// Forward declarations for internal functions
void watchdogSetup(void);
bool readDebugButton();
bool readUserButton();
void debugLED(bool on);
void activateDisplay(bool on);
double readBatteryVoltageInternal();
bool objectDetected();
bool checkForDaylight();
void resetMemoryInternal();

void initSensors() {
  // DEBUG_PRINTLN(F("Initialisiere Sensormodul")); // Removed DEBUG_PRINTLN

  pinMode(PHOTODIODE_ON, OUTPUT);
  pinMode(PHOTODIODE, INPUT);
  pinMode(LIGHTBARRIER_ON, OUTPUT);
  pinMode(LIGHTBARRIER, INPUT);
  pinMode(LIGHTBARRIER2, INPUT);
  pinMode(DEBUG_BUTTON, INPUT_PULLUP);
  //Pin6 is not arduino API compatible, need to set it manually for USER_BUTTON:
  DDRB &= ~(1 << PB6);  //input
  PORTB |= (1 << PB6);  //pullup

  digitalWrite(PHOTODIODE_ON, HIGH);
  digitalWrite(LIGHTBARRIER_ON, HIGH);
  debugLED(OFF); // Ensure debug LED is off initially

  // Check for reset memory on startup
  if (readDebugButton()) {
    resetMemoryInternal();
  }

  // overallCount and todayCount are initialized and managed by the Counter module
  // No need to read them here

  watchdogSetup(); // Setup watchdog for power down mode
  activateDisplay(true); // Turn on display initially
}

bool checkBarrier() {
  long startContact = millis();
  bool detection = false;
  permanentBlocked = false;
  while (objectDetected()) {
    detection = true;
    if (millis() > startContact + 2000) {
      permanentBlocked = true;
      // DEBUG_PRINTLN(F("Permanent Blocked!")); // Removed DEBUG_PRINTLN
      return false;
    }
  }
  if (detection) {
    lastContactDuration = millis() - startContact;
    incrementCounts(); // Delegate to Counter module to update todayCount and overallCount
    
    // DEBUG_PRINTF("Contact! Today: %d, Overall: %ld, Duration: %ldms\n", getTodayCount(), getOverallCount(), lastContactDuration); // Removed DEBUG_PRINTF
    
    // Quick debug LED blinks
    debugLED(true);
    delay(50);
    debugLED(false);
    delay(50);
    debugLED(true);
    delay(50);
    debugLED(false);
    delay(50);
    debugLED(true);
    delay(50);
    debugLED(false);
    return true; // Indicate a new detection
  }
  return false; // No new detection
}

bool isPermanentBlocked() {
  return permanentBlocked;
}

void handleSleepAndDaylight() {
  if (displayOn && millisDisplayOff < millis()) {
    activateDisplay(false); // Turn off display if timeout reached
  }

  if (isDay) {
    if (nextMillisToCheckForDaylight < millis()) {
      checkForDaylight();    
      nextMillisToCheckForDaylight = millis() + CHECK_FOR_DAYLIGHT_EVERY; // Reset timer for next check
    }
  } else {  // If it's night
    wdt_reset();
    set_sleep_mode(SLEEP_MODE_PWR_DOWN);  // choose power down mode
    sleep_mode();                         // sleep now!

    if (pwrdwnCycles++ > CYCLES_TO_WAIT) {  // After CYCLES_TO_WAIT wakeups by the watchdog timer, check for brightness
      pwrdwnCycles = 0;
      delay(100); // Small delay after wakeup before checking sensor
      checkForDaylight();
    }
  }
}

void handleButtonPresses() {
  if (readDebugButton()) {
    debugLED(true);
    activateDisplay(true); // Turn on display for debug output
    // DEBUG_PRINTLN(F("Debug Button Pressed. Showing debug info.")); // Removed DEBUG_PRINTLN
    delay(200);
    debugLED(false);
  }

  if (readUserButton()) {
    resetPage(); // Delegate to Counter module to reset page
    debugLED(true);
    activateDisplay(true); // Turn on display for user output
    // DEBUG_PRINTLN(F("User Button Pressed. Showing info.")); // Removed DEBUG_PRINTLN
    delay(200);
    debugLED(false);
  }
}

int getBrightness() {
  digitalWrite(PHOTODIODE_ON, HIGH);
  delay(25); // Give sensor time to settle
  int brightness = analogRead(PHOTODIODE);
  digitalWrite(PHOTODIODE_ON, LOW);
  return brightness;
}

bool getIsDay() {
  return isDay;
}

int getBatteryLevel() {
  double voltage = readBatteryVoltageInternal();
  // Assuming a 12V lead-acid battery or similar
  // Adjust these values based on the actual battery type and its charge curve
  if (voltage >= 12.7) return 100; // Fully charged
  if (voltage >= 12.5) return 90;
  if (voltage >= 12.3) return 80;
  if (voltage >= 12.0) return 70;
  if (voltage >= 11.8) return 60;
  if (voltage >= 11.6) return 50;
  if (voltage >= 11.4) return 40;
  if (voltage >= 11.2) return 30;
  if (voltage >= 11.0) return 20;
  if (voltage >= 10.8) return 10;
  return 0; // Critically low
}


// --- Internal Helper Functions from original sketch ---
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

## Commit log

2023-05-23 Bugfix for pwrdwn (int overflow)
    [MTB-Lightbarrier.ino]
2023-05-31 Corrected comment about fuses
    [MTB-Lightbarrier.ino]
2025-06-03 circuit added
    [Schaltplan.brd, Schaltplan.sch]

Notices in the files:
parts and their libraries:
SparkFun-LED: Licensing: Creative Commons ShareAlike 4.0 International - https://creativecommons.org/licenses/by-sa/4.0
